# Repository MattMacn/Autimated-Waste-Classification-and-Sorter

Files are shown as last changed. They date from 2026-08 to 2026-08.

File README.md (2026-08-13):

# Automated Material Sorting System

## Overview

The **Automated Material Sorting System** is an embedded system designed to automatically identify and sort different types of waste.

The system uses an **ESP32 microcontroller** together with inductive, capacitive and ultrasonic sensors to identify materials and control a mechanical sorting mechanism using four servo motors.

The project combines **embedded software, electronics, PCB design and mechanical control** into a single automated system.

## Features

* Automatic material detection
* Metal detection using an inductive sensor
* Non-metal material detection using a capacitive sensor
* Ultrasonic sensing for object detection
* Automated mechanical sorting
* Four servo motors for material routing
* ESP32-based embedded control
* Custom PCB designed using KiCad
* Separate collection compartments for different materials

## System Architecture

```text

                            ^
                            |
          +-----------------+-----------------+
          |                 |                 |
          v                 v                 v
   +-------------+   +-------------+   +-------------+
   |  Inductive  |   | Capacitive  |   |  Ultrasonic |
   |   Sensor    |   |   Sensor    |   |   Sensor    |
   +-------------+   +-------------+   +-------------+
          +-----------------+-----------------+
                            |                 
                            |                                       
                            |
                            v
                  +-------------------+
                  |       ESP32       |
                  |                   |
                  |  Embedded Control |
                  +---------+---------+
                            |
                            v
                   +----------------+
                   | Material       |
                   | Classification |
                   +-------+--------+
                           |
                           v
                  +-------------------+
                  | Servo Actuators   |
                  |                   |
                  |   4 x SG90        |
                  +---------+---------+

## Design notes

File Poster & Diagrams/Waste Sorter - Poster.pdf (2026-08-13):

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

# Material Recycling Sorter

A low-cost automated prototype that identifies and sorts three common recyclable materials into a bin; metal, glass, and paper. Accomplished using a gravity-fed chute, an array of proximity sensors, and servo-actuated gates controlled by an ESP32 microcontroller. Designed to reduce contamination at the source, improve recycling accuracy, and demonstrate sustainable engineering principles in a clear, accessible way.

S E N S O R S

Inductive Proximity (IPS)

Detects metal via eddy current damping

Capacitive Proximity (CAP)

Separates glass (εr 7.5) from paper (εr 2.4)

Ultrasonic HC-SR04

Presence detection <10 cm to trigger sequence

S D G 12 A L I G N M E N T

Target 12.5 - Substantially reduce waste generation through recycling and reuse.

Target 12.8 - Ensure public awareness for sustainable development. The manual mode lets users operate gates directly, making the sorting logic tangible and educational.

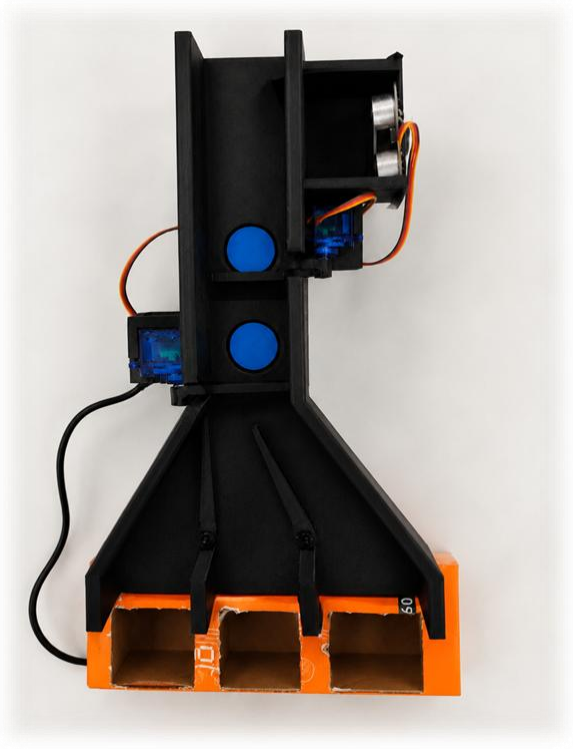
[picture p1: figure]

A U T O M O D E 6-step non-blocking state machine on ESP32

M A N U A L
M O D E | Buttons & potentiometer for interactive demos

K E Y F E A T U R E S

Servo-Actuated Gates

4 × SG90 servos powered at 6V for increased torque, directing items into the correct bin via sequential gate opening.

3D-Printed Chute

Gravity-fed CAD-designed structure with integrated servo housings, sensor ports, and custom horn attachments.

CX318 Group Project · 2025/26

Sorting: Metal · Glass · Paper

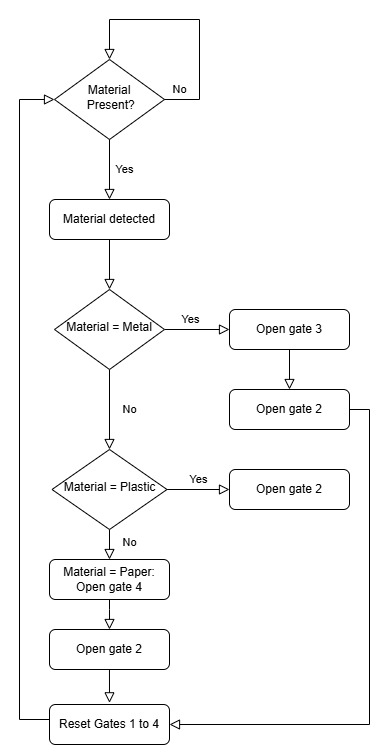
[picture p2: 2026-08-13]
Poster & Diagrams/Waste Sorter - High Level Software Flow Chart.jpg

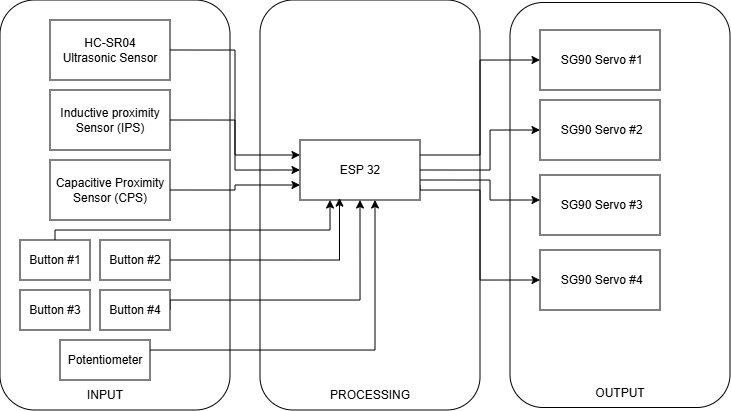
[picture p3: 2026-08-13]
Poster & Diagrams/Waste Sorter - Functional Block Diagram.drawio.png

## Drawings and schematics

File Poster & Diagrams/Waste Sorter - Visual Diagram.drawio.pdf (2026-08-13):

# Waste Sorter Visual Diagram

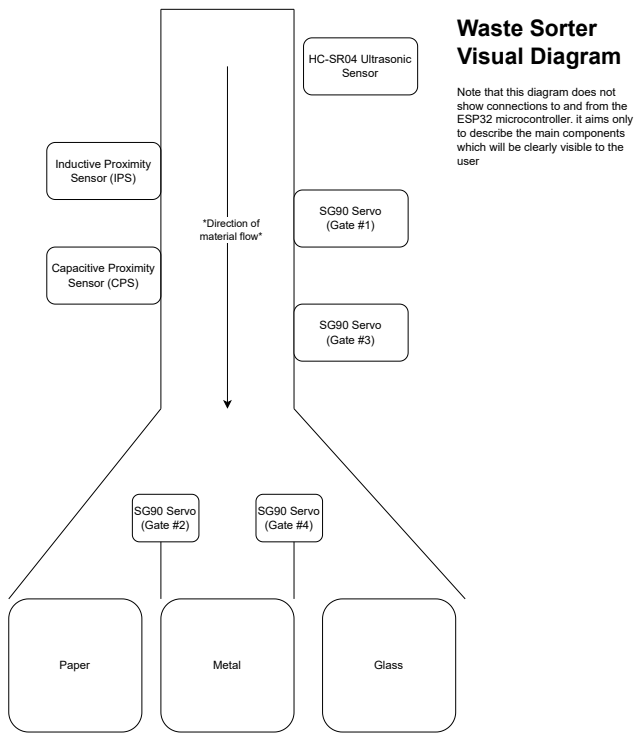
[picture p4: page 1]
Inductive Proximity Sensor (IPS); Capacitive Proximity Sensor (CPS); HC-SR04 Ultrasonic Sensor; SG90 Servo (Gate #1); SG90 Servo (Gate #2); SG90 Servo (Gate #3); SG90 Servo (Gate #4); *Direction of material flow*; Paper; Metal; Glass

Note that this diagram does not
show connections to and from the
ESP32 microcontroller. it aims only
to describe the main components
which will be clearly visible to the
user

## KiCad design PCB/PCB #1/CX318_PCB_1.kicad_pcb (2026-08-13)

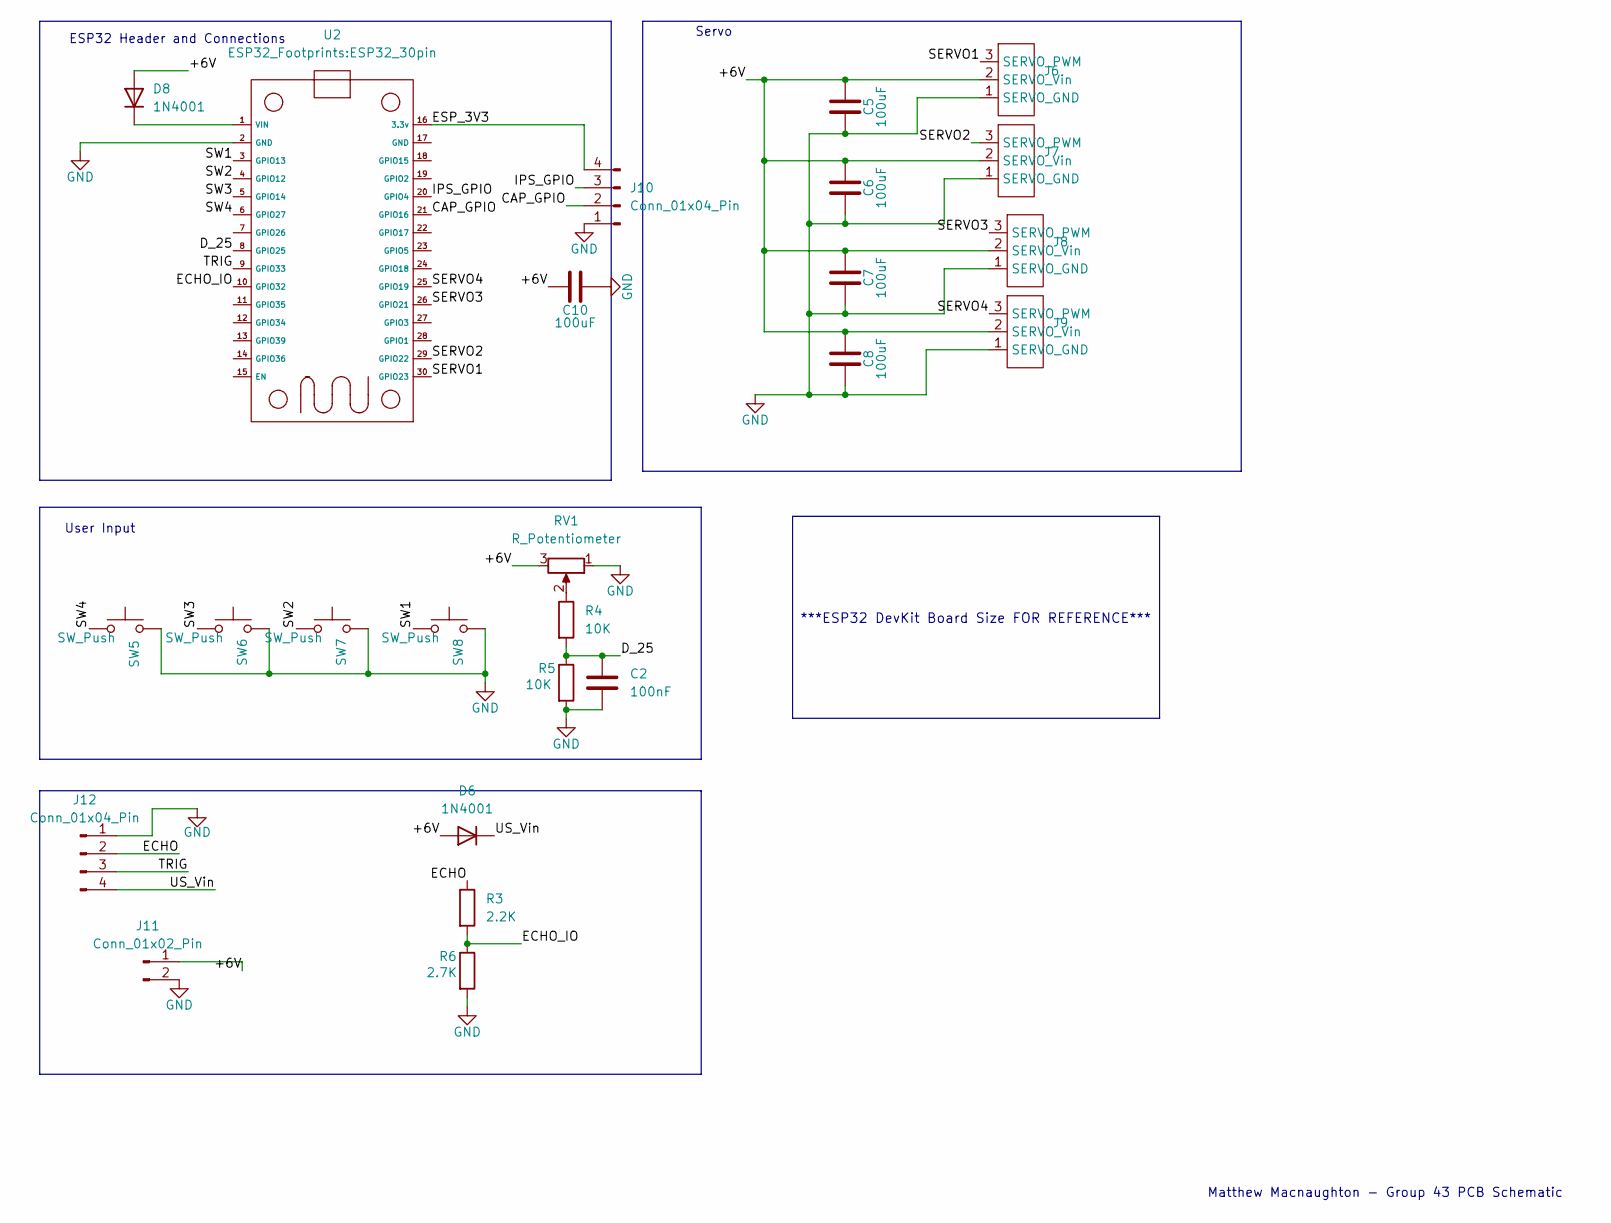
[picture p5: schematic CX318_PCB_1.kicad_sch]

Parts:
C2: 100nF; C_Disc_D5.0mm_W2.5mm_P5.00mm
C5, C6, C7, C8, C10: 100uF; C_Disc_D5.0mm_W2.5mm_P5.00mm
D6, D8: 1N4001; D_DO-41_SOD81_P10.16mm_Horizontal
J6, J7, J8, J9: PinHeader_1x03_P2.54mm_Vertical
J10: Conn_01x04_Pin; JST_XH_B4B-XH-A_1x04_P2.50mm_Vertical
J11: Conn_01x02_Pin; PinSocket_1x02_P2.54mm_Vertical
J12: Conn_01x04_Pin; PinSocket_1x04_P2.54mm_Vertical
R3: 2.2K; R_Axial_DIN0207_L6.3mm_D2.5mm_P7.62mm_Horizontal
R4, R5: 10K; R_Axial_DIN0207_L6.3mm_D2.5mm_P7.62mm_Horizontal
R6: 2.7K; R_Axial_DIN0207_L6.3mm_D2.5mm_P7.62mm_Horizontal
RV1: R_Potentiometer; Potentiometer_Bourns_3386P_Vertical
SW5, SW6, SW7, SW8: SW_Push; SW_PUSH_6mm
U2: ESP32_30pin

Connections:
/+6V: C5.1, C6.1, C7.1, C8.1, C10.2, D6.2 (A), D8.2 (A), J6.2 (SERVO_Vin), J7.2 (SERVO_Vin), J8.2 (SERVO_Vin), J9.2 (SERVO_Vin), J11.1, RV1.3
/CAP_GPIO: J10.2, U2.21 (GPIO16)
/D_25: C2.1, R4.2, R5.1, U2.8 (GPIO25)
/ECHO: J12.2, R3.1
/ECHO_IO: R3.2, R6.1, U2.10 (GPIO32)
/ESP_3V3: J10.4, U2.16 (3.3v)
/IPS_GPIO: J10.3, U2.20 (GPIO4)
/SERVO1: J6.3 (SERVO_PWM), U2.30 (GPIO23)
/SERVO2: J7.3 (SERVO_PWM), U2.29 (GPIO22)
/SERVO3: J8.3 (SERVO_PWM), U2.26 (GPIO21)
/SERVO4: J9.3 (SERVO_PWM), U2.25 (GPIO19)
/SW1: SW8.1, U2.3 (GPIO13)
/SW2: SW7.1, U2.4 (GPIO12)
/SW3: SW6.1, U2.5 (GPIO14)
/SW4: SW5.1, U2.6 (GPIO27)
/TRIG: J12.3, U2.9 (GPIO33)
/US_Vin: D6.1 (K), J12.4
GND: C2.2, C5.2, C6.2, C7.2, C8.2, C10.1, J6.1 (SERVO_GND), J7.1 (SERVO_GND), J8.1 (SERVO_GND), J9.1 (SERVO_GND), J10.1, J11.2, J12.1, R5.2, R6.2, RV1.1, SW5.2, SW6.2, SW7.2, SW8.2, U2.2 (GND)
unnamed: D8.1 (K), U2.1 (VIN)
unnamed: R4.1, RV1.2

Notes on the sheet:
User Input
Matthew Macnaughton - Group 43 PCB Schematic
Servo
ESP32 Header and Connections
***ESP32 DevKit Board Size FOR REFERENCE***

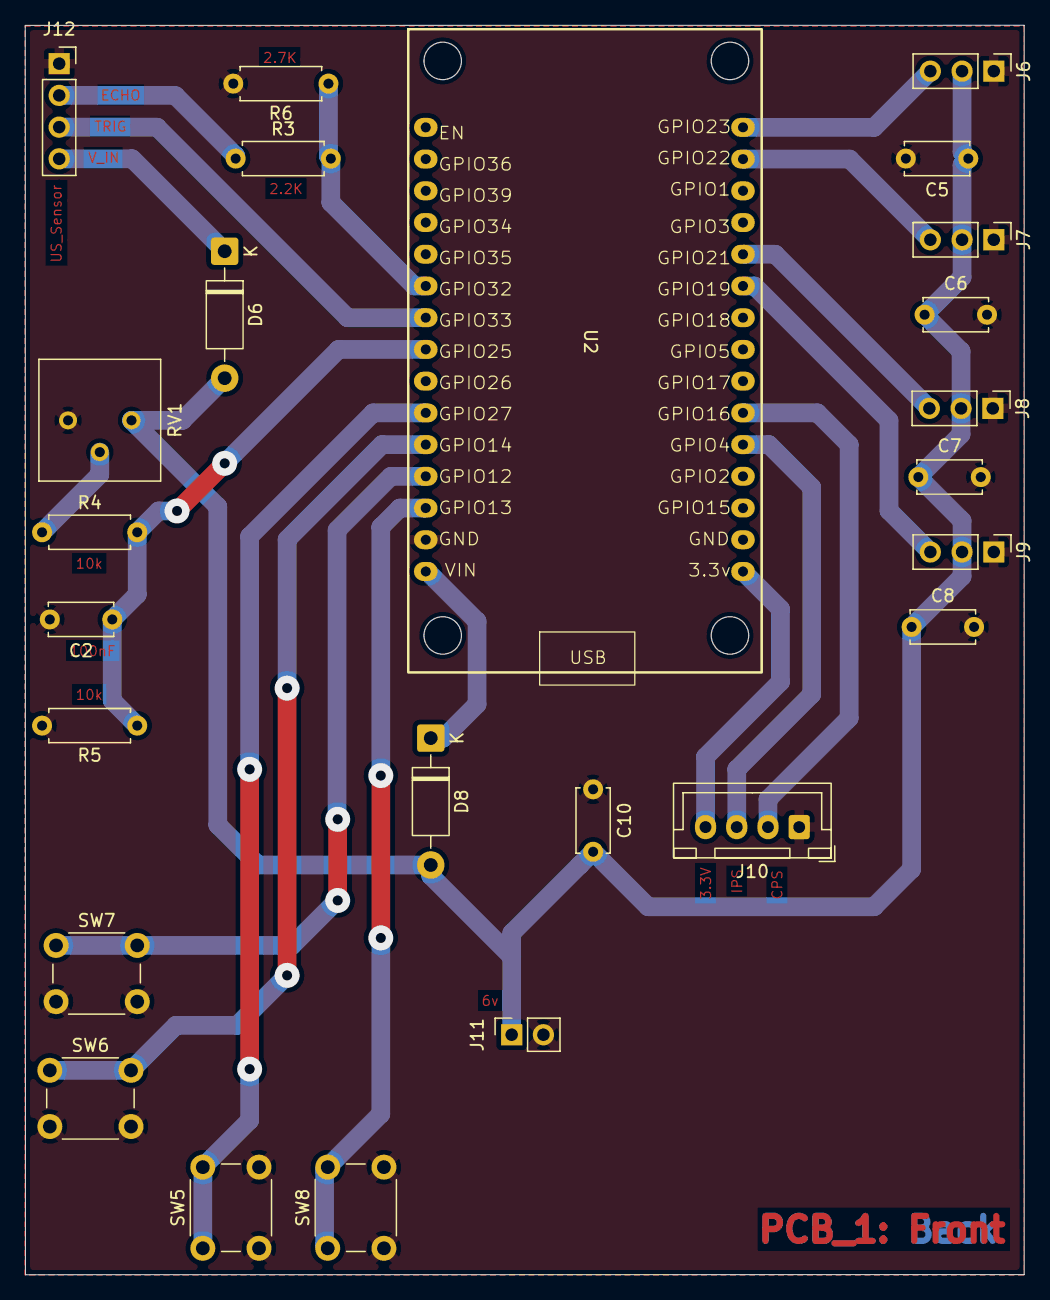
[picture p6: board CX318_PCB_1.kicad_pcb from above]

Board: 2 copper layers, 80.0 x 100.0 mm, 25 parts (0 on the bottom side), 20 nets.

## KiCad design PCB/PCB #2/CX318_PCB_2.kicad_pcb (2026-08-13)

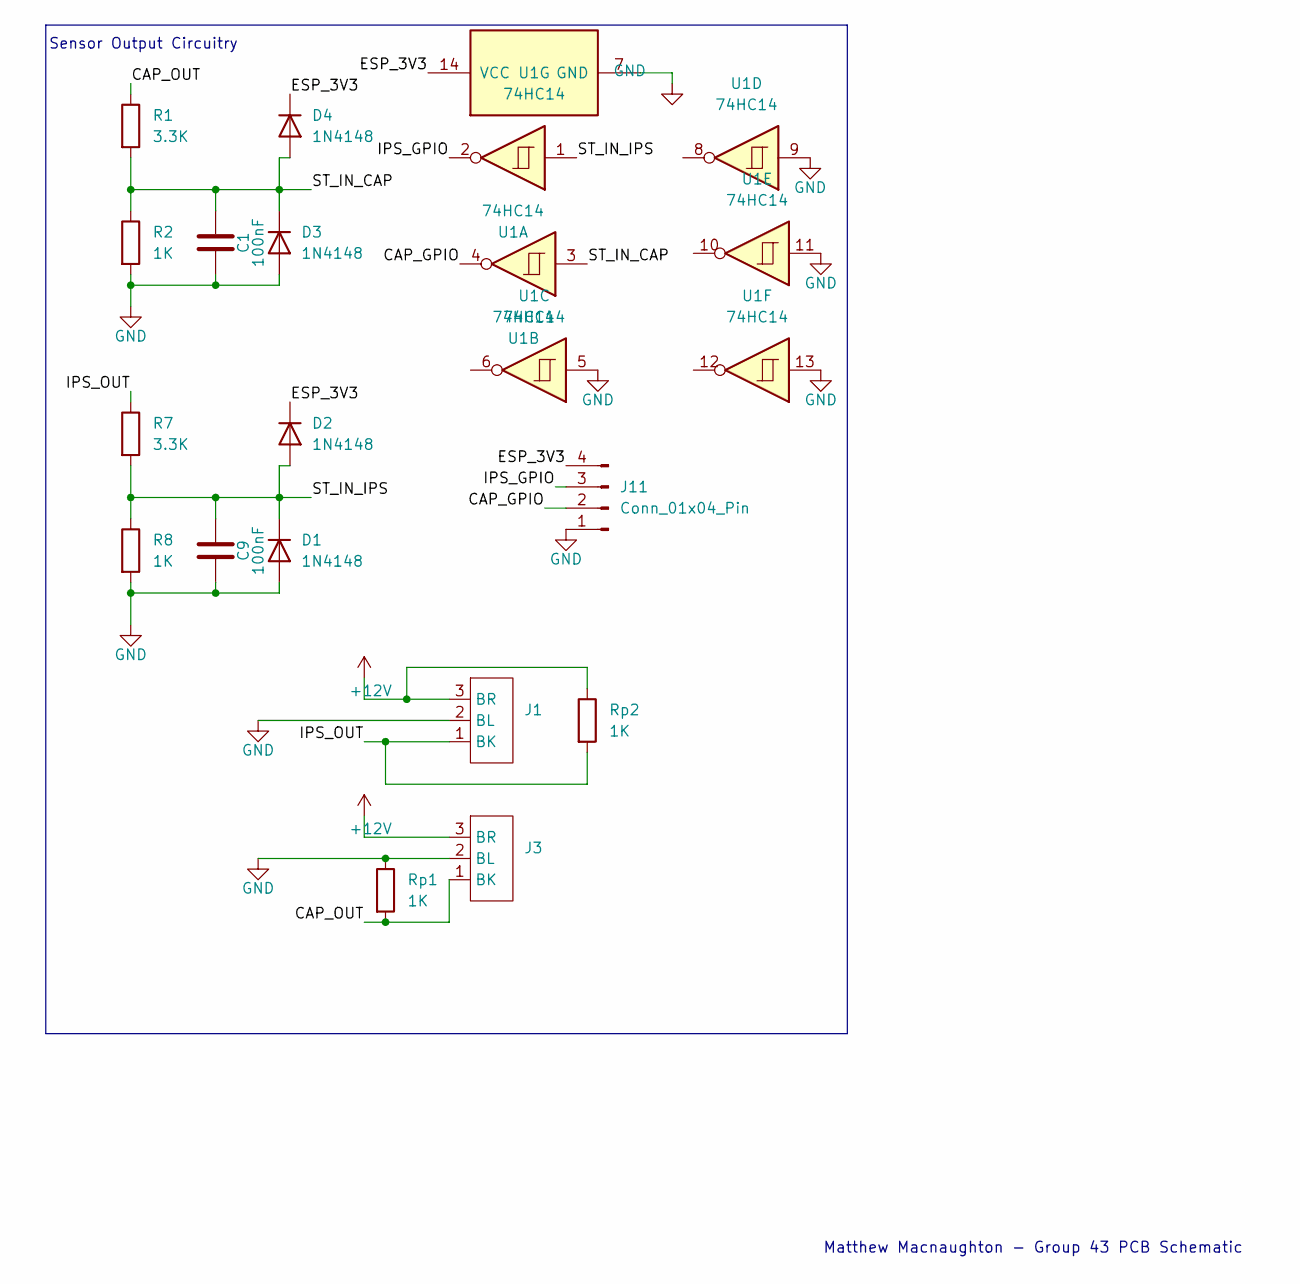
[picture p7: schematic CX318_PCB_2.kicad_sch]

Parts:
C1, C9: 100nF; C_Disc_D5.0mm_W2.5mm_P5.00mm
D1, D2, D3, D4: 1N4148; D_DO-35_SOD27_P7.62mm_Horizontal
J1, J3: PinHeader_1x03_P2.54mm_Vertical
J11: Conn_01x04_Pin; JST_XH_B4B-XH-A_1x04_P2.50mm_Vertical
R1, R7: 3.3K; R_Axial_DIN0207_L6.3mm_D2.5mm_P7.62mm_Horizontal
R2, R8: 1K; R_Axial_DIN0207_L6.3mm_D2.5mm_P7.62mm_Horizontal
Rp1, Rp2: 1K; R_Axial_DIN0207_L6.3mm_D2.5mm_P7.62mm_Horizontal
U1: 74HC14; DIP-14_W7.62mm

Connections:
+12V: J1.3 (BR), J3.3 (BR), Rp2.1; also elsewhere on the board
/CAP_GPIO: J11.2, U1.4
/CAP_OUT: J3.1 (BK), R1.1, Rp1.2
/ESP_3V3: D2.1 (K), D4.1 (K), J11.4, U1.14 (VCC)
/IPS_GPIO: J11.3, U1.2
/IPS_OUT: J1.1 (BK), R7.1, Rp2.2
/ST_IN_CAP: C1.1, D3.1 (K), D4.2 (A), R1.2, R2.1, U1.3
/ST_IN_IPS: C9.1, D1.1 (K), D2.2 (A), R7.2, R8.1, U1.1
GND: C1.2, C9.2, D1.2 (A), D3.2 (A), J1.2 (BL), J3.2 (BL), J11.1, R2.2, R8.2, Rp1.1, U1.5, U1.7 (GND), U1.9, U1.11, U1.13; also elsewhere on the board

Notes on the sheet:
Matthew Macnaughton - Group 43 PCB Schematic
Sensor Output Circuitry

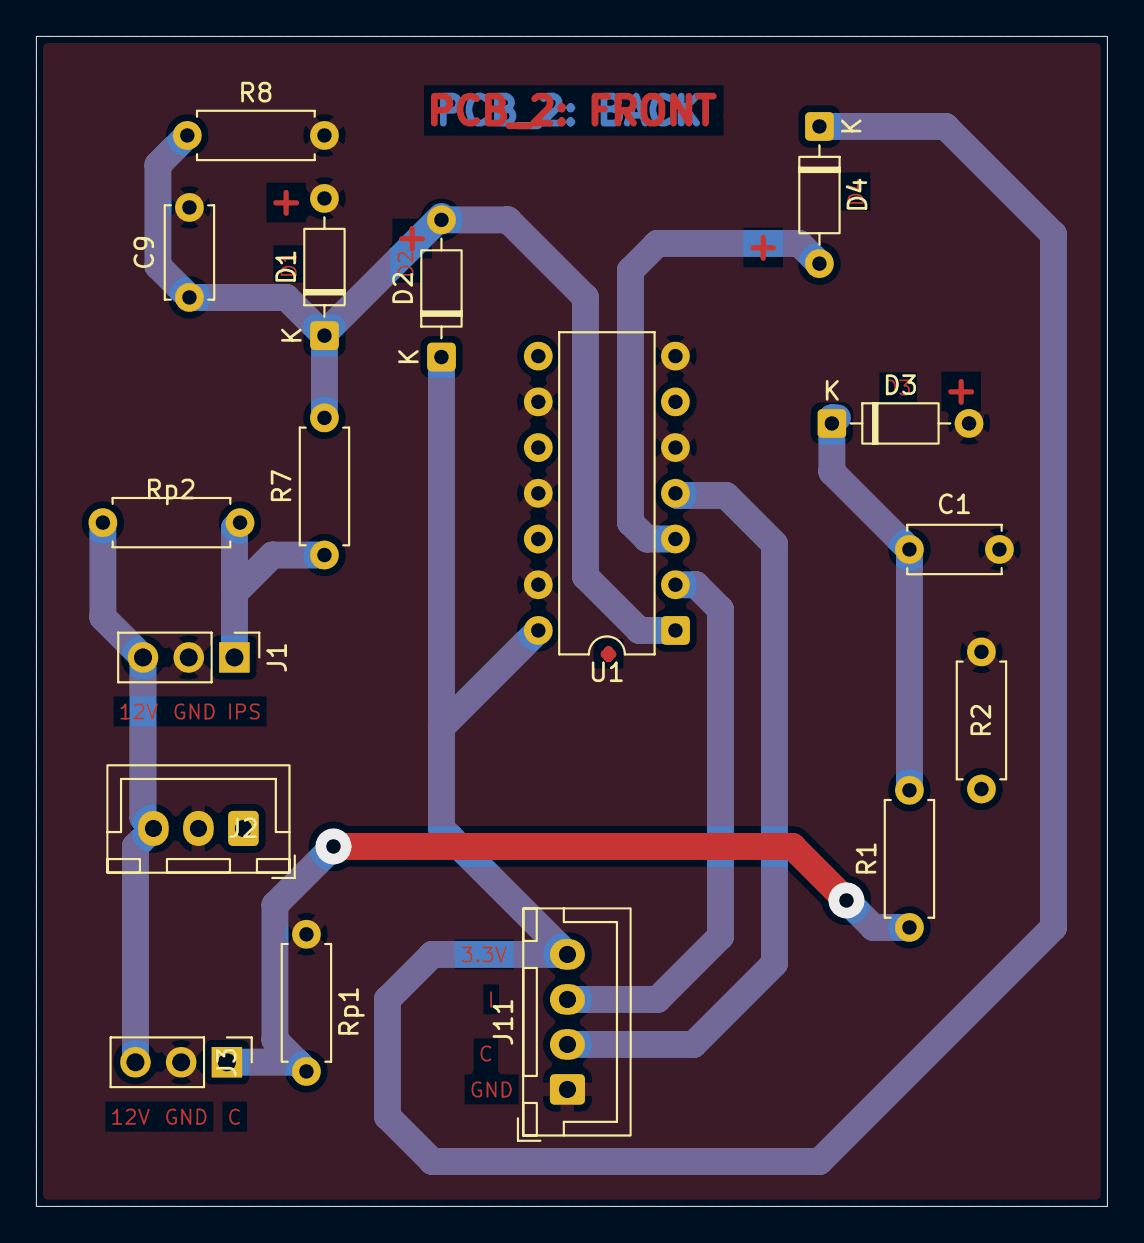
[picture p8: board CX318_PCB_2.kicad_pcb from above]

Board: 2 copper layers, 59.5 x 65.0 mm, 17 parts (0 on the bottom side), 9 nets.

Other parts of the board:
J2: Conn_01x03_Pin; JST_XH_B3B-XH-A_1x03_P2.50mm_Vertical

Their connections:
+12V: J2.3; also elsewhere on the board
GND: J2.2; also elsewhere on the board
